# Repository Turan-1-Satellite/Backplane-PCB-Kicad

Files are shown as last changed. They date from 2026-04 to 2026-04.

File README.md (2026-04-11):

# Turan-1 Backplane PCB in KiCad
## About
This repository contains the KiCad 9.0 project files for the TURAN-1 Backplane PCB.

## Requirements
- KiCad 9.0 or later

## First Set up
All required custom libraries and 3D models are included as a git submodule. To clone the repository together with custom libraries, you need to recursively clone it:
```
git clone --recurse-submodules https://github.com/Turan-1-Satellite/Backplane-PCB-Kicad.git
```

## Open the Project
Open the BP-PCB-Kicad.kicad_pro file from the project root directory.

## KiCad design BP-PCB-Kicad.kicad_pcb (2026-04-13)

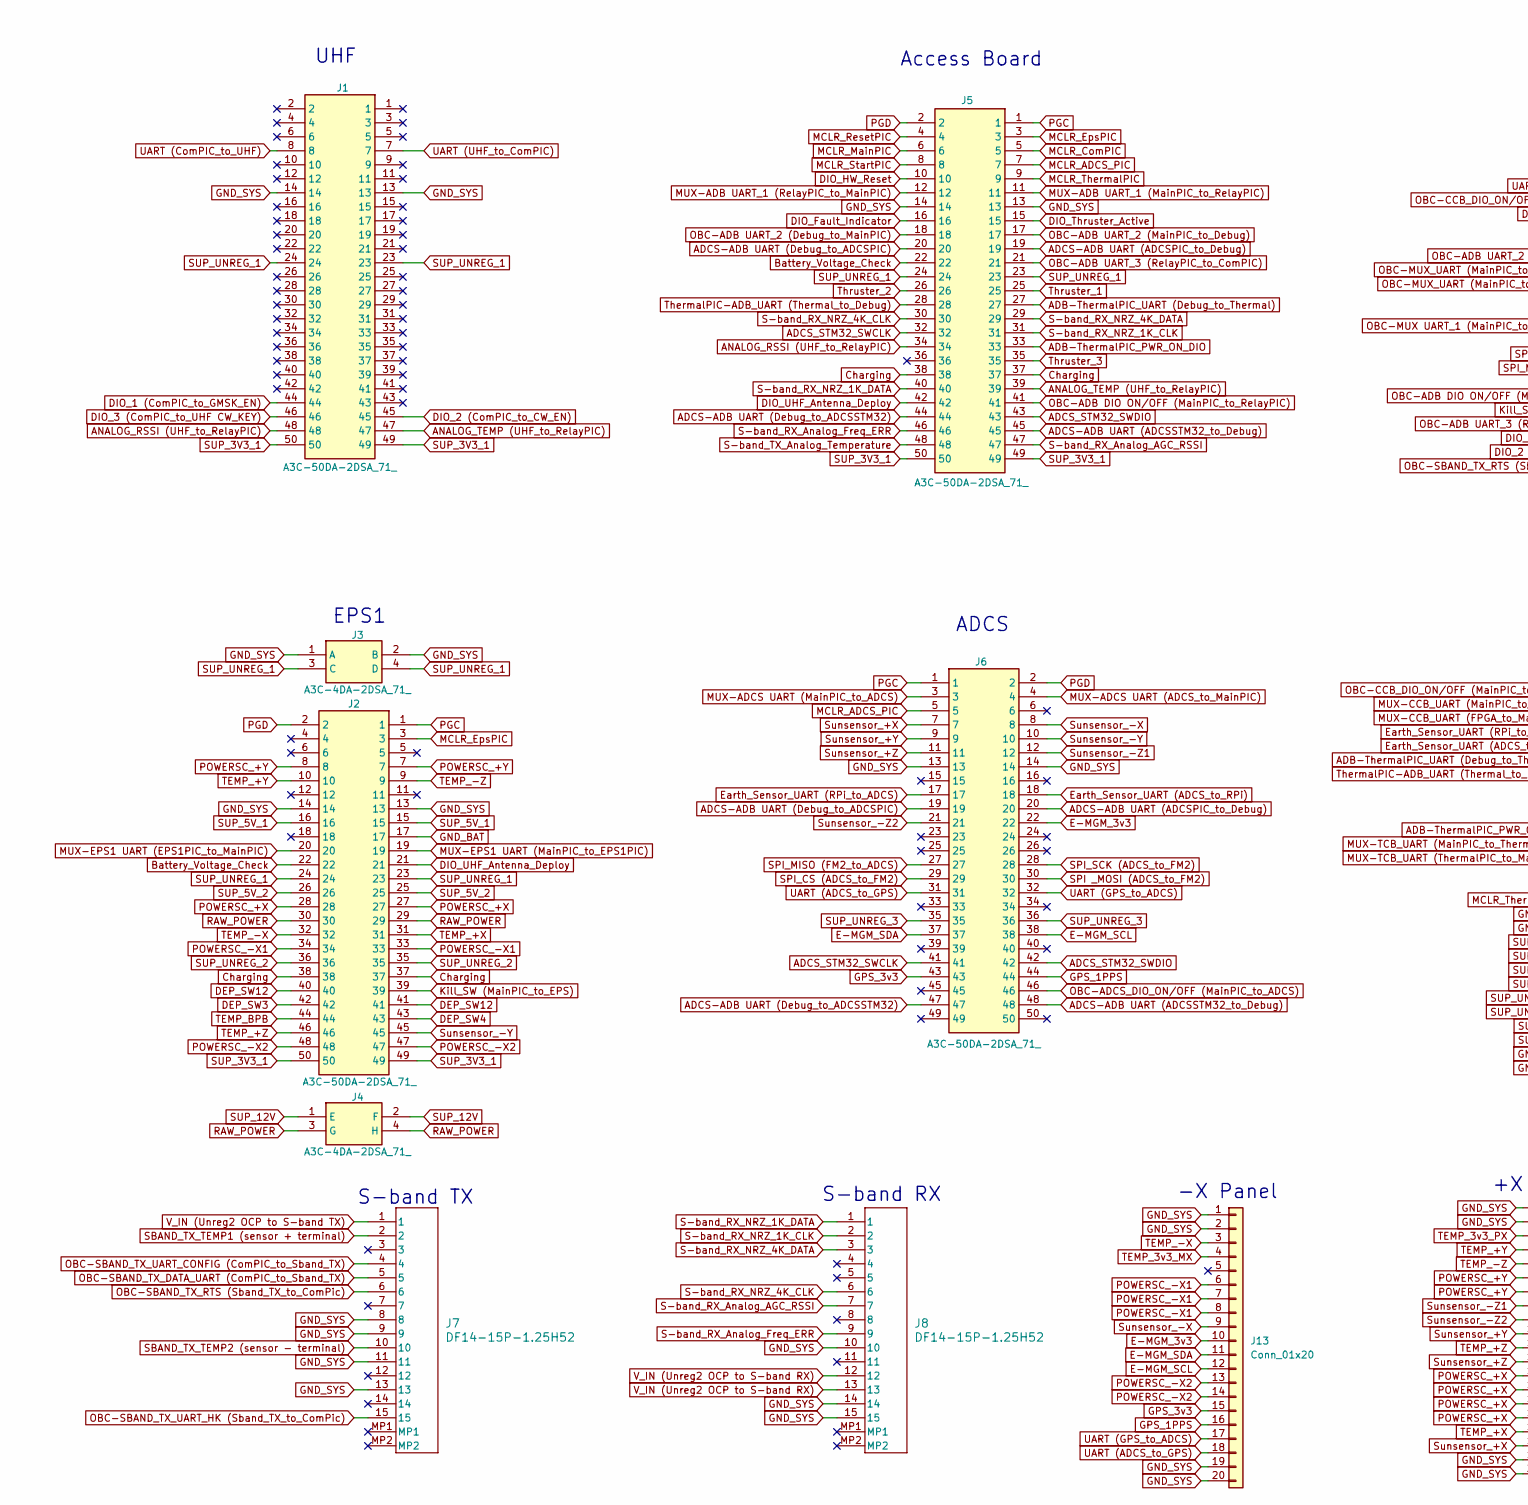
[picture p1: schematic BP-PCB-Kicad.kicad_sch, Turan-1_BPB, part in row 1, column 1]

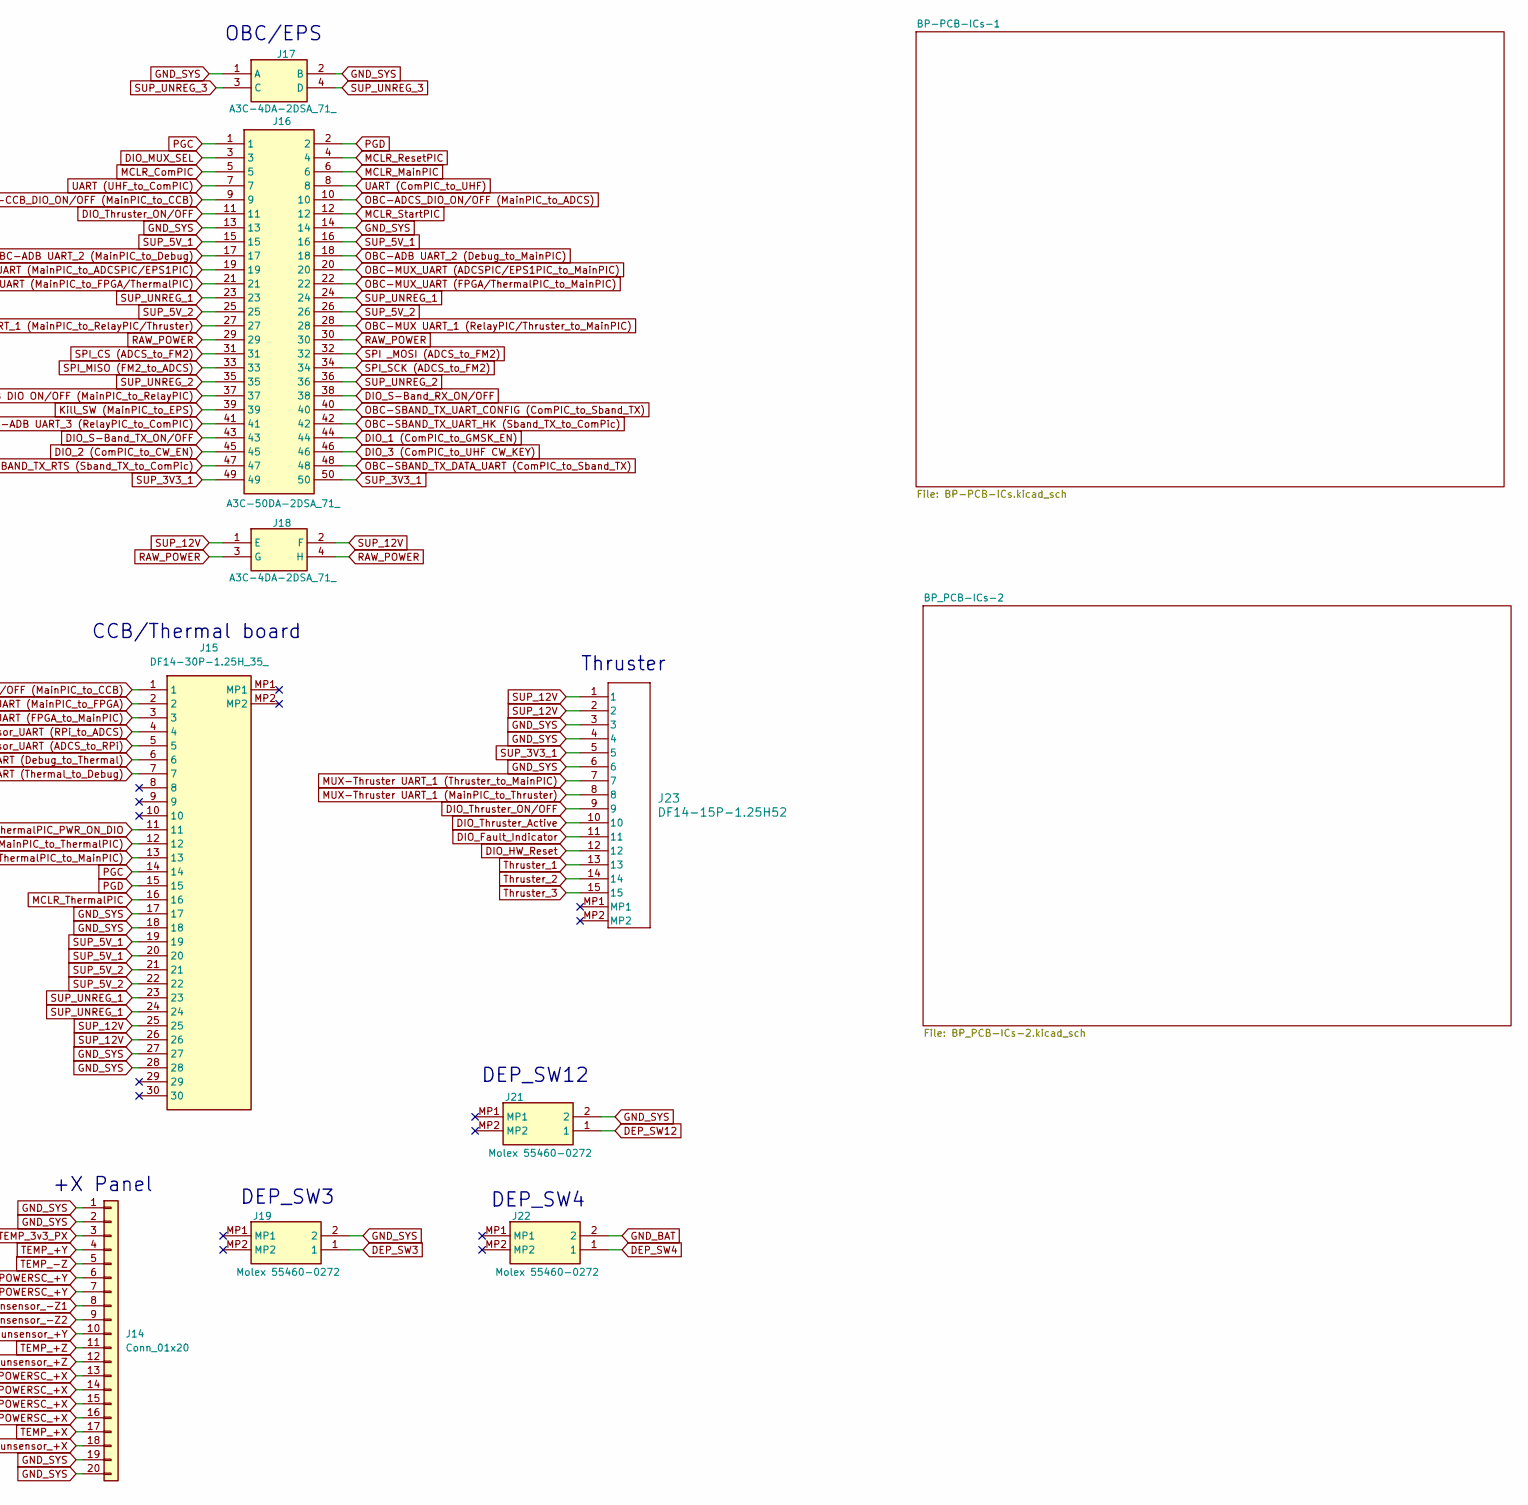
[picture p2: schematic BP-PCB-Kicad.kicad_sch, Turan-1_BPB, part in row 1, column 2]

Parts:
J1, J2, J5: A3C-50DA-2DSA_71_; Hirose_A3C-50DA-2DSC(71)_Mirrored; Mouser Part Number 798-A3C-50DA-2DSA71
J3, J4: A3C-4DA-2DSA_71_; Hirose_A3C-4DA-2DSA(71)_Mirrored; Mouser Part Number 798-A3C-4DA-2DSA71
J6, J16: A3C-50DA-2DSA_71_; Hirose_A3C-50DA-2DSC(71); Mouser Part Number 798-A3C-50DA-2DSA71
J7, J8, J23: DF14-15P-1.25H52; Hirose_DF14-15P-1.25H(52)
J13: Conn_01x20; PSR-420253-10
J14: Conn_01x20; PSR-420253-10_Mirrored
J15: DF14-30P-1.25H_35_; Hirose_DF14-30P-1.25H(35); Mouser Part Number 798-DF1430P125H35
J17, J18: A3C-4DA-2DSA_71_; Hirose_A3C-4DA-2DSA(71); Mouser Part Number 798-A3C-4DA-2DSA71
J19, J21, J22: Molex 55460-0272; Molex_0554600272; Mouser Part Number 538-55460-0272

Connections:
V_IN (Unreg2 OCP to S-band RX): J8.12, J8.13; also elsewhere on the board
V_IN (Unreg2 OCP to S-band TX): J7.1; also elsewhere on the board
ADB-ThermalPIC_PWR_ON_DIO: J5.33, J15.11
ADB-ThermalPIC_UART (Debug_to_Thermal): J5.27, J15.6
ADCS-ADB UART (ADCSPIC_to_Debug): J5.19, J6.20
ADCS-ADB UART (ADCSSTM32_to_Debug): J5.45, J6.48
ADCS-ADB UART (Debug_to_ADCSPIC): J5.20, J6.19
ADCS-ADB UART (Debug_to_ADCSSTM32): J5.44, J6.47
ADCS_STM32_SWCLK: J5.32, J6.41
ADCS_STM32_SWDIO: J5.43, J6.42
ANALOG_RSSI (UHF_to_RelayPIC): J1.48, J5.34
ANALOG_TEMP (UHF_to_RelayPIC): J1.47, J5.39
Battery_Voltage_Check: J2.22, J5.22
Charging: J2.37, J2.38, J5.37, J5.38
DEP_SW3: J2.42, J19.1
DEP_SW4: J2.43, J22.1
DEP_SW12: J2.40, J2.41, J21.1
DIO_1 (ComPIC_to_GMSK_EN): J1.44, J16.44
DIO_2 (ComPIC_to_CW_EN): J1.45, J16.45
DIO_3 (ComPIC_to_UHF CW_KEY): J1.46, J16.46
DIO_Fault_Indicator: J5.16, J23.11
DIO_HW_Reset: J5.10, J23.12
DIO_MUX_SEL: J16.3; also elsewhere on the board
DIO_S-Band_RX_ON/OFF: J16.38; also elsewhere on the board
DIO_S-Band_TX_ON/OFF: J16.43; also elsewhere on the board
DIO_Thruster_Active: J5.15, J23.10
DIO_Thruster_ON/OFF: J16.11, J23.9
DIO_UHF_Antenna_Deploy: J2.21, J5.42
E-MGM_3v3: J6.22, J13.10
E-MGM_SCL: J6.38, J13.12
E-MGM_SDA: J6.37, J13.11
Earth_Sensor_UART (ADCS_to_RPi): J6.18, J15.5
Earth_Sensor_UART (RPi_to_ADCS): J6.17, J15.4
GND_BAT: J2.17, J22.2
GND_SYS: J1.13, J1.14, J2.13, J2.14, J3.1 (A), J3.2 (B), J5.13, J5.14, J6.13, J6.14, J7.8, J7.9, J7.11, J7.13, J8.10, J8.14, J8.15, J13.1, J13.2, J13.19, J13.20, J14.1, J14.2, J14.19, J14.20, J15.17, J15.18, J15.27, J15.28, J16.13, J16.14, J17.1 (A), J17.2 (B), J19.2, J21.2, J23.3, J23.4, J23.6; also elsewhere on the board
GPS_1PPS: J6.44, J13.16
GPS_3v3: J6.43, J13.15
Kill_SW (MainPIC_to_EPS): J2.39, J16.39
MCLR_ADCS_PIC: J5.7, J6.5
MCLR_ComPIC: J5.5, J16.5
MCLR_EpsPIC: J2.3, J5.3
MCLR_MainPIC: J5.6, J16.6
MCLR_ResetPIC: J5.4, J16.4
MCLR_StartPIC: J5.8, J16.12
MCLR_ThermalPIC: J5.9, J15.16
MUX-ADB UART_1 (MainPIC_to_RelayPIC): J5.11; also elsewhere on the board
MUX-ADB UART_1 (RelayPIC_to_MainPIC): J5.12; also elsewhere on the board
MUX-ADCS UART (ADCS_to_MainPIC): J6.4; also elsewhere on the board
MUX-ADCS UART (MainPIC_to_ADCS): J6.3; also elsewhere on the board
MUX-CCB_UART (FPGA_to_MainPIC): J15.3; also elsewhere on the board
MUX-CCB_UART (MainPIC_to_FPGA): J15.2; also elsewhere on the board
MUX-EPS1 UART (EPS1PIC_to_MainPIC): J2.20; also elsewhere on the board
MUX-EPS1 UART (MainPIC_to_EPS1PIC): J2.19; also elsewhere on the board
MUX-TCB_UART (MainPIC_to_ThermalPIC): J15.12; also elsewhere on the board
MUX-TCB_UART (ThermalPIC_to_MainPIC): J15.13; also elsewhere on the board
MUX-Thruster UART_1 (MainPIC_to_Thruster): J23.8; also elsewhere on the board
MUX-Thruster UART_1 (Thruster_to_MainPIC): J23.7; also elsewhere on the board
OBC-ADB DIO ON/OFF (MainPIC_to_RelayPIC): J5.41, J16.37
OBC-ADB UART_2 (Debug_to_MainPIC): J5.18, J16.18
OBC-ADB UART_2 (MainPIC_to_Debug): J5.17, J16.17
OBC-ADB UART_3 (RelayPIC_to_ComPIC): J5.21, J16.41
OBC-ADCS_DIO_ON/OFF (MainPIC_to_ADCS): J6.46, J16.10
OBC-CCB_DIO_ON/OFF (MainPIC_to_CCB): J15.1, J16.9
OBC-MUX UART_1 (MainPIC_to_RelayPIC/Thruster): J16.27; also elsewhere on the board
OBC-MUX UART_1 (RelayPIC/Thruster_to_MainPIC): J16.28; also elsewhere on the board
OBC-MUX_UART (ADCSPIC/EPS1PIC_to_MainPIC): J16.20; also elsewhere on the board
OBC-MUX_UART (FPGA/ThermalPIC_to_MainPIC): J16.22; also elsewhere on the board
OBC-MUX_UART (MainPIC_to_ADCSPIC/EPS1PIC): J16.19; also elsewhere on the board
OBC-MUX_UART (MainPIC_to_FPGA/ThermalPIC): J16.21; also elsewhere on the board
OBC-SBAND_TX_DATA_UART (ComPIC_to_Sband_TX): J7.5, J16.48
OBC-SBAND_TX_RTS (Sband_TX_to_ComPic): J7.6, J16.47
OBC-SBAND_TX_UART_CONFIG (ComPIC_to_Sband_TX): J7.4, J16.40
OBC-SBAND_TX_UART_HK (Sband_TX_to_ComPic): J7.15, J16.42
PGC: J2.1, J5.1, J6.1, J15.14, J16.1
PGD: J2.2, J5.2, J6.2, J15.15, J16.2
POWERSC_+X: J2.27, J2.28, J14.13, J14.14, J14.15, J14.16
POWERSC_+Y: J2.7, J2.8, J14.6, J14.7
POWERSC_-X1: J2.33, J2.34, J13.6, J13.7, J13.8
POWERSC_-X2: J2.47, J2.48, J13.13, J13.14
RAW_POWER: J2.29, J2.30, J4.3 (G), J4.4 (H), J16.29, J16.30, J18.3 (G), J18.4 (H)
S-band_RX_Analog_AGC_RSSI: J5.47, J8.7
S-band_RX_Analog_Freq_ERR: J5.46, J8.9
S-band_RX_NRZ_1K_CLK: J5.31, J8.2
S-band_RX_NRZ_1K_DATA: J5.40, J8.1
S-band_RX_NRZ_4K_CLK: J5.30, J8.6
S-band_RX_NRZ_4K_DATA: J5.29, J8.3
S-band_TX_Analog_Temperature: J5.48, J7.10; also elsewhere on the board
SBAND_TX_TEMP1 (sensor + terminal): J7.2; also elsewhere on the board
SPI _MOSI (ADCS_to_FM2): J6.30, J16.32
SPI_CS (ADCS_to_FM2): J6.29, J16.31
SPI_MISO (FM2_to_ADCS): J6.27, J16.33
SPI_SCK (ADCS_to_FM2): J6.28, J16.34
SUP_3V3_1: J1.49, J1.50, J2.49, J2.50, J5.49, J5.50, J16.49, J16.50, J23.5; also elsewhere on the board
SUP_5V_1: J2.15, J2.16, J15.19, J15.20, J16.15, J16.16; also elsewhere on the board
SUP_5V_2: J2.25, J2.26, J15.21, J15.22, J16.25, J16.26
SUP_12V: J4.1 (E), J4.2 (F), J15.25, J15.26, J18.1 (E), J18.2 (F), J23.1, J23.2
SUP_UNREG_1: J1.23, J1.24, J2.23, J2.24, J3.3 (C), J3.4 (D), J5.23, J5.24, J15.23, J15.24, J16.23, J16.24
SUP_UNREG_2: J2.35, J2.36, J16.35, J16.36; also elsewhere on the board
SUP_UNREG_3: J6.35, J6.36, J17.3 (C), J17.4 (D)
Sunsensor_+X: J6.7, J14.18
Sunsensor_+Y: J6.9, J14.10
Sunsensor_+Z: J6.11, J14.12
Sunsensor_-X: J6.8, J13.9
Sunsensor_-Y: J2.45, J6.10
Sunsensor_-Z1: J6.12, J14.8
Sunsensor_-Z2: J6.21, J14.9
TEMP_3v3_MX: J13.4; also elsewhere on the board
TEMP_3v3_PX: J14.3; also elsewhere on the board
TEMP_+X: J2.31, J14.17
TEMP_+Y: J2.10, J14.4
TEMP_+Z: J2.46, J14.11
TEMP_-X: J2.32, J13.3
TEMP_-Z: J2.9, J14.5
TEMP_BPB: J2.44; also elsewhere on the board
ThermalPIC-ADB_UART (Thermal_to_Debug): J5.28, J15.7
Thruster_1: J5.25, J23.13
Thruster_2: J5.26, J23.14
Thruster_3: J5.35, J23.15
UART (ADCS_to_GPS): J6.31, J13.18
UART (ComPIC_to_UHF): J1.8, J16.8
UART (GPS_to_ADCS): J6.32, J13.17
UART (UHF_to_ComPIC): J1.7, J16.7

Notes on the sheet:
DEP_SW4
OBC/EPS
ADCS
S-band TX
EPS1
DEP_SW3
+X Panel
CCB/Thermal board
DEP_SW12
S-band RX
UHF
Access Board
Thruster
-X Panel

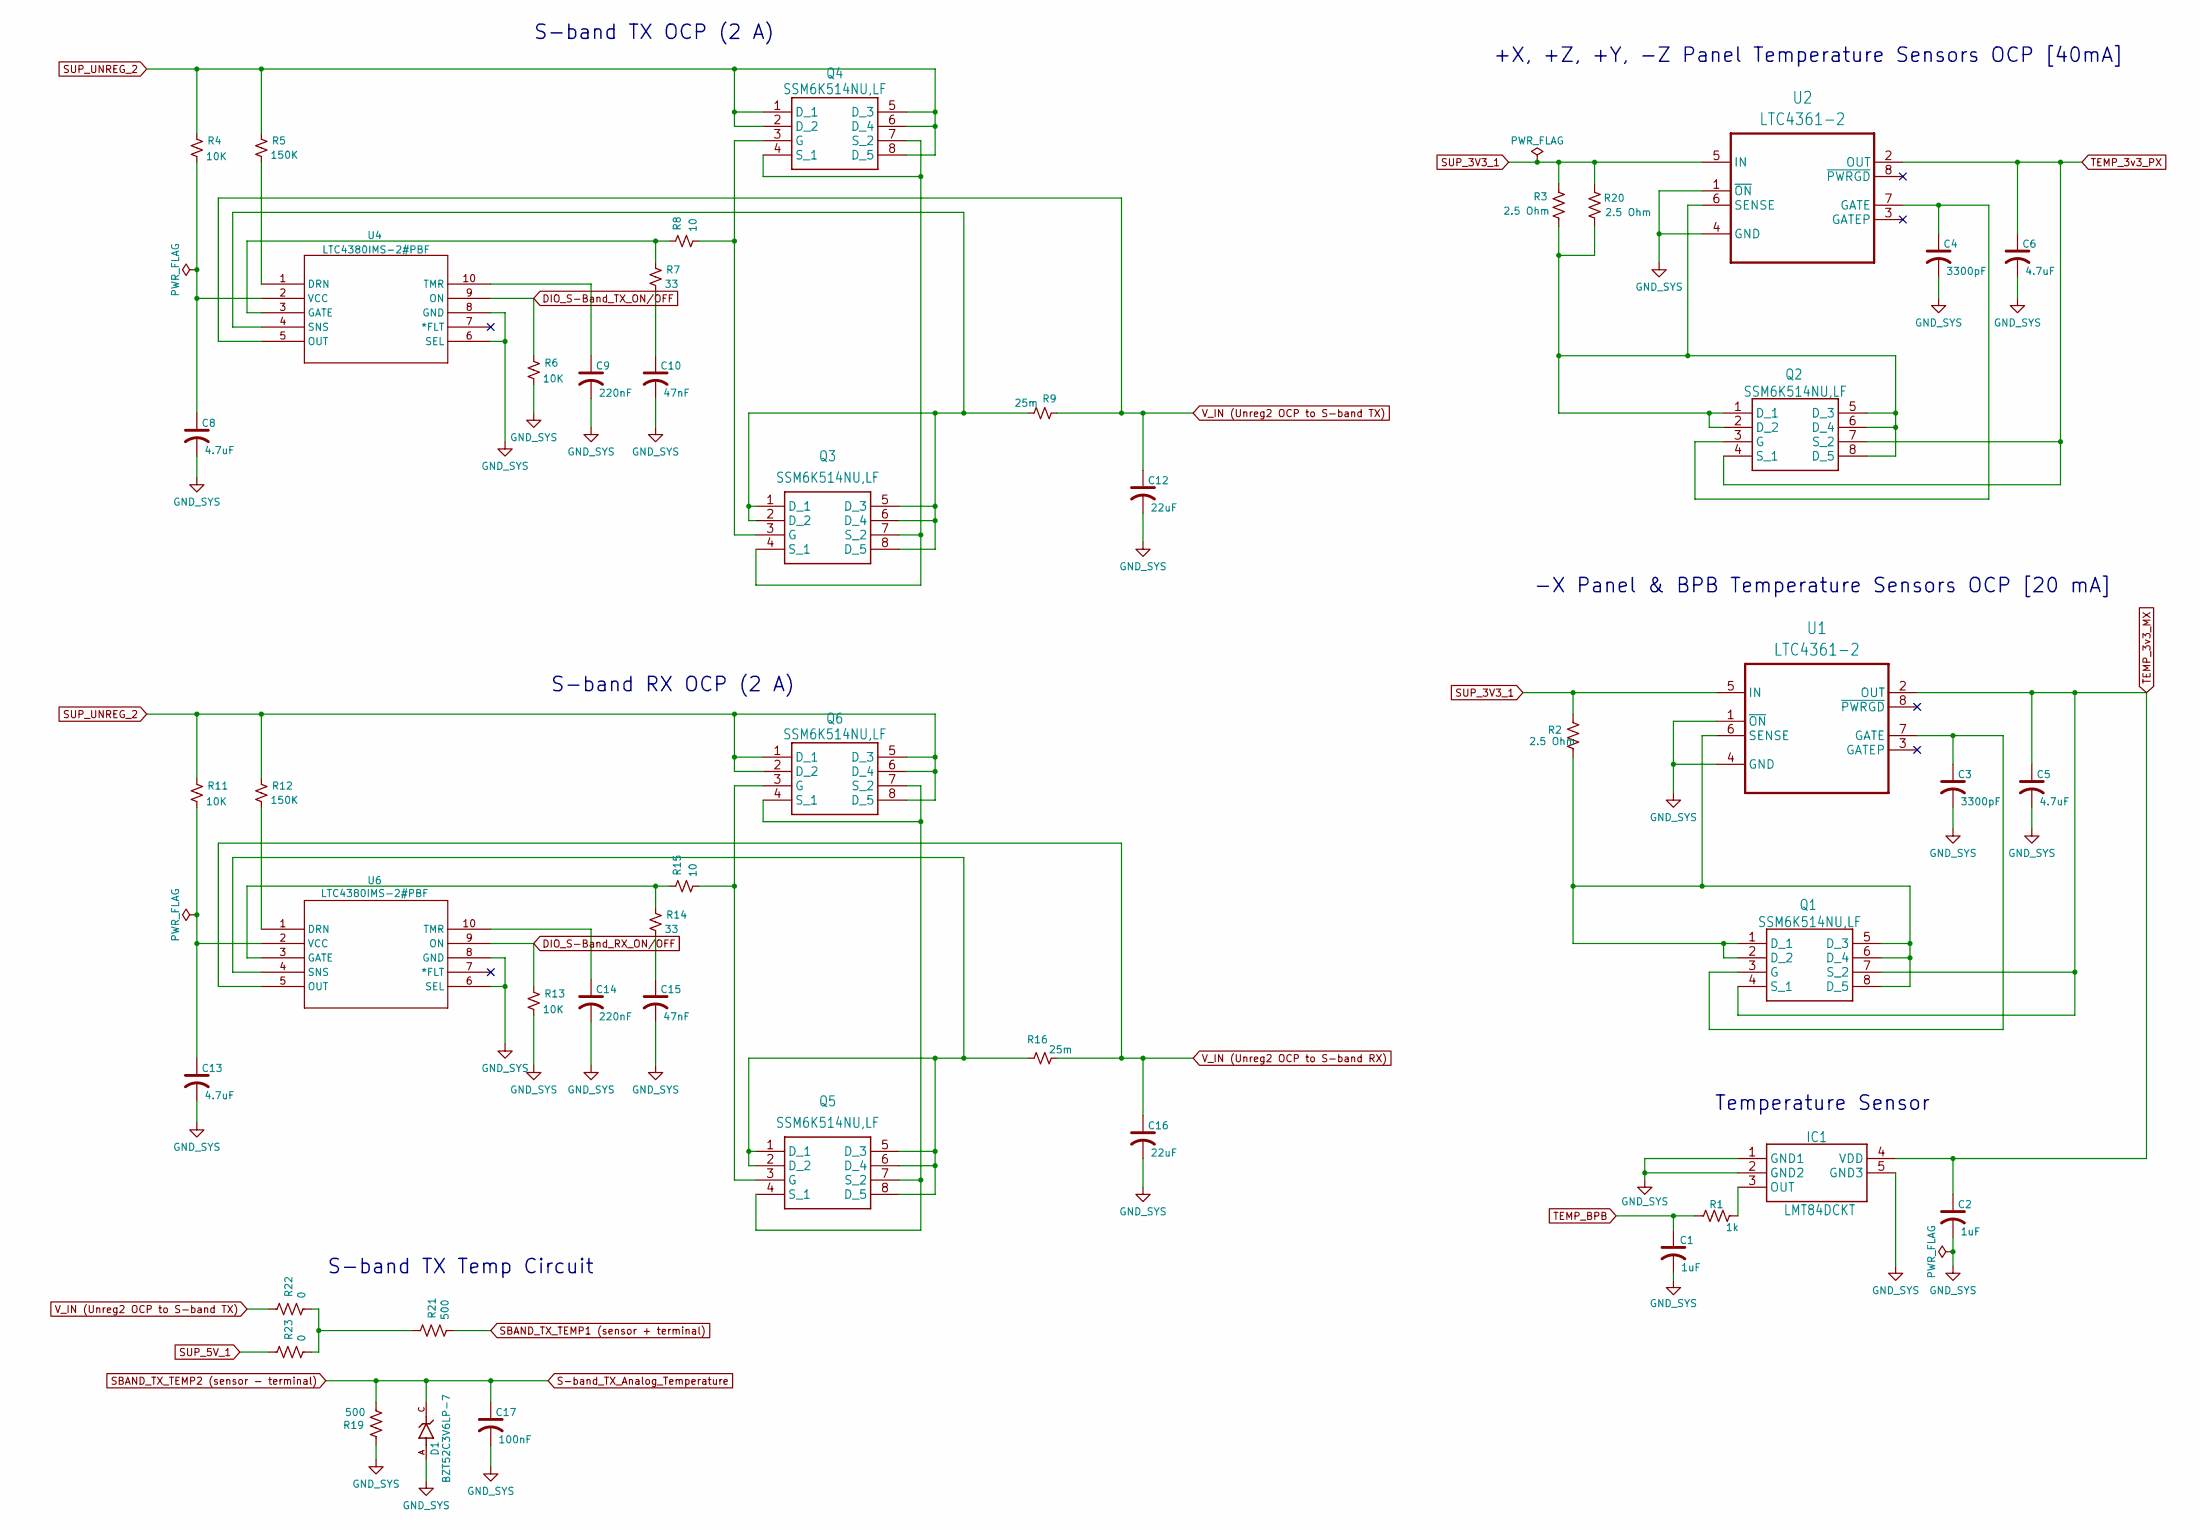
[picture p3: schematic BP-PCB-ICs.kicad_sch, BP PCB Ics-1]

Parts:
C1, C2: 1uF; C_0805_2012Metric; LCSC Part C1712
C3, C4: 3300pF; C_0805_2012Metric; LCSC Part C77062
C5, C6, C8, C13: 4.7uF; C_0805_2012Metric; LCSC Part C1746
C9, C14: 220nF; C_0805_2012Metric; LCSC Part C1770
C10, C15: 47nF; C_0805_2012Metric; LCSC Part C1745
C12, C16: 22uF; C_0805_2012Metric; LCSC Part C45783
C17: 100nF; C_0805_2012Metric; LCSC Part C29926
D1: BZT52C3V6LP-7; DIO_BZT52C3V6LP-7; LCSC Part C151430
IC1: LMT84DCKT; LCSC Part C2860524
Q1, Q2, Q3, Q4, Q5, Q6: SSM6K514NU,LF; SSM6K514NULF; LCSC Part C6235373
R1: 1k; R_0805_2012Metric; LCSC Part C702831
R2, R3, R20: 2.5 Ohm; R_0805_2012Metric; LCSC Part C409739
R4, R6, R11, R13: 10K; R_0805_2012Metric; LCSC Part C702829
R5, R12: 150K; R_0805_2012Metric; LCSC Part C17470
R7, R14: 33; R_0805_2012Metric; LCSC Part C49330262
R8, R15: 10; R_0805_2012Metric; LCSC Part C702857
R9, R16: 25m; R_0805_2012Metric; LCSC Part C858607
R19, R21: 500; R_0805_2012Metric; LCSC Part C2828711
R22: 0; R_0805_2012Metric
R23: 0; R_0805_2012Metric; LCSC Part C702869
U1, U2: LTC4361-2; LTC4361HTS8; LCSC Part C688273
U4, U6: LTC4380IMS-2#PBF; LCSC Part C688471

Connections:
V_IN (Unreg2 OCP to S-band RX): C16.1, R16.2, U6.5 (OUT); also elsewhere on the board
V_IN (Unreg2 OCP to S-band TX): C12.1, R9.2, R22.1, U4.5 (OUT); also elsewhere on the board
DIO_S-Band_RX_ON/OFF: R13.1, U6.9 (ON); also elsewhere on the board
DIO_S-Band_TX_ON/OFF: R6.1, U4.9 (ON); also elsewhere on the board
GND_SYS: C1.2, C2.2, C3.2, C4.2, C5.2, C6.2, C8.2, C9.2, C10.2, C12.2, C13.2, C14.2, C15.2, C16.2, C17.2, D1.A, IC1.1 (GND1), IC1.2 (GND2), IC1.5 (GND3), R6.2, R13.2, R19.1, U1.1 (~ON), U1.4 (GND), U2.1 (~ON), U2.4 (GND), U4.6 (SEL), U4.8 (GND), U6.6 (SEL), U6.8 (GND); also elsewhere on the board
unnamed: C10.1, R7.2
unnamed: C15.1, R14.2
unnamed: IC1.3 (OUT), R1.2
unnamed: Q1.1 (D_1), Q1.2 (D_2), Q1.5 (D_3), Q1.6 (D_4), Q1.8 (D_5), R2.2, U1.6 (SENSE)
unnamed: C3.1, Q1.3 (G), U1.7 (GATE)
unnamed: Q2.1 (D_1), Q2.2 (D_2), Q2.5 (D_3), Q2.6 (D_4), Q2.8 (D_5), R3.2, R20.2, U2.6 (SENSE)
unnamed: C4.1, Q2.3 (G), U2.7 (GATE)
unnamed: Q3.1 (D_1), Q3.2 (D_2), Q3.5 (D_3), Q3.6 (D_4), Q3.8 (D_5), R9.1, U4.4 (SNS)
unnamed: Q3.3 (G), Q4.3 (G), R8.2
unnamed: Q3.4 (S_1), Q3.7 (S_2), Q4.4 (S_1), Q4.7 (S_2)
unnamed: Q5.1 (D_1), Q5.2 (D_2), Q5.5 (D_3), Q5.6 (D_4), Q5.8 (D_5), R16.1, U6.4 (SNS)
unnamed: Q5.3 (G), Q6.3 (G), R15.2
unnamed: Q5.4 (S_1), Q5.7 (S_2), Q6.4 (S_1), Q6.7 (S_2)
unnamed: R21.1, R22.2, R23.2
unnamed: R5.2, U4.1 (DRN)
unnamed: R7.1, R8.1, U4.3 (GATE)
unnamed: C9.1, U4.10 (TMR)
unnamed: C8.1, R4.2, U4.2 (VCC)
unnamed: R12.2, U6.1 (DRN)
unnamed: R14.1, R15.1, U6.3 (GATE)
unnamed: C14.1, U6.10 (TMR)
unnamed: C13.1, R11.2, U6.2 (VCC)
S-band_TX_Analog_Temperature: C17.1, D1.C, R19.2; also elsewhere on the board
SBAND_TX_TEMP1 (sensor + terminal): R21.2; also elsewhere on the board
SUP_3V3_1: R2.1, R3.1, R20.1, U1.5 (IN), U2.5 (IN); also elsewhere on the board
SUP_5V_1: R23.1; also elsewhere on the board
SUP_UNREG_2: Q4.1 (D_1), Q4.2 (D_2), Q4.5 (D_3), Q4.6 (D_4), Q4.8 (D_5), Q6.1 (D_1), Q6.2 (D_2), Q6.5 (D_3), Q6.6 (D_4), Q6.8 (D_5), R4.1, R5.1, R11.1, R12.1; also elsewhere on the board
TEMP_3v3_MX: C2.1, C5.1, IC1.4 (VDD), Q1.4 (S_1), Q1.7 (S_2), U1.2 (OUT); also elsewhere on the board
TEMP_3v3_PX: C6.1, Q2.4 (S_1), Q2.7 (S_2), U2.2 (OUT); also elsewhere on the board
TEMP_BPB: C1.1, R1.1; also elsewhere on the board

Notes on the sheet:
S-band TX Temp Circuit
Temperature Sensor
+X, +Z, +Y, -Z Panel Temperature Sensors OCP [40mA]
-X Panel & BPB Temperature Sensors OCP [20 mA]
S-band TX OCP (2 A)
S-band RX OCP (2 A)

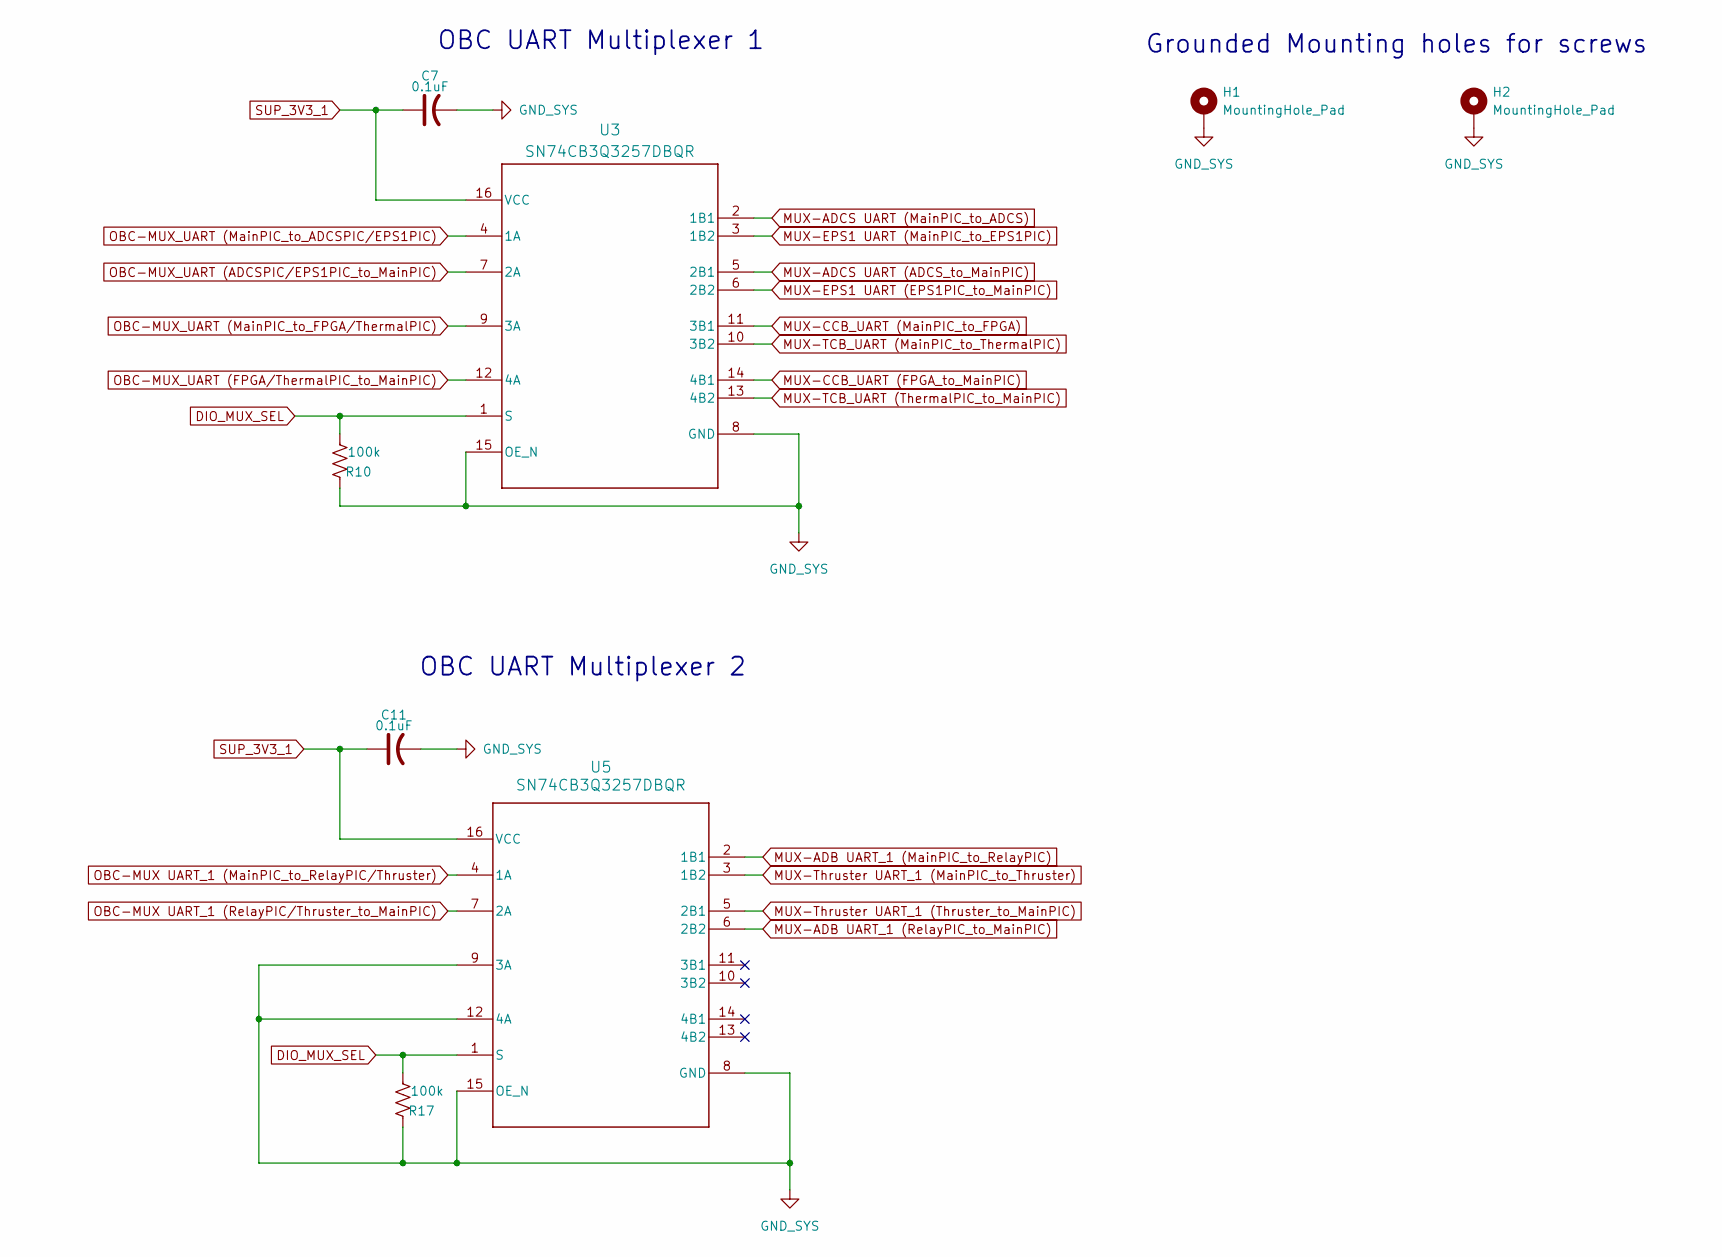
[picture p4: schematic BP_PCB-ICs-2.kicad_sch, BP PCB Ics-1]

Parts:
C7, C11: 0.1uF; C_0805_2012Metric; LCSC Part C1711
H1, H2: MountingHole_Pad; MountingHole_2.7mm_Pad
R10, R17: 100k; R_0805_2012Metric; LCSC Part C409739
U3, U5: SN74CB3Q3257DBQR; LCSC Part C7138

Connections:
DIO_MUX_SEL: R10.2, R17.2, U3.1 (S), U5.1 (S); also elsewhere on the board
GND_SYS: C7.2, C11.2, H1.1, H2.1, R10.1, R17.1, U3.8 (GND), U3.15 (OE_N), U5.8 (GND), U5.9 (3A), U5.12 (4A), U5.15 (OE_N); also elsewhere on the board
MUX-ADB UART_1 (MainPIC_to_RelayPIC): U5.2 (1B1); also elsewhere on the board
MUX-ADB UART_1 (RelayPIC_to_MainPIC): U5.6 (2B2); also elsewhere on the board
MUX-ADCS UART (ADCS_to_MainPIC): U3.5 (2B1); also elsewhere on the board
MUX-ADCS UART (MainPIC_to_ADCS): U3.2 (1B1); also elsewhere on the board
MUX-CCB_UART (FPGA_to_MainPIC): U3.14 (4B1); also elsewhere on the board
MUX-CCB_UART (MainPIC_to_FPGA): U3.11 (3B1); also elsewhere on the board
MUX-EPS1 UART (EPS1PIC_to_MainPIC): U3.6 (2B2); also elsewhere on the board
MUX-EPS1 UART (MainPIC_to_EPS1PIC): U3.3 (1B2); also elsewhere on the board
MUX-TCB_UART (MainPIC_to_ThermalPIC): U3.10 (3B2); also elsewhere on the board
MUX-TCB_UART (ThermalPIC_to_MainPIC): U3.13 (4B2); also elsewhere on the board
MUX-Thruster UART_1 (MainPIC_to_Thruster): U5.3 (1B2); also elsewhere on the board
MUX-Thruster UART_1 (Thruster_to_MainPIC): U5.5 (2B1); also elsewhere on the board
OBC-MUX UART_1 (MainPIC_to_RelayPIC/Thruster): U5.4 (1A); also elsewhere on the board
OBC-MUX UART_1 (RelayPIC/Thruster_to_MainPIC): U5.7 (2A); also elsewhere on the board
OBC-MUX_UART (ADCSPIC/EPS1PIC_to_MainPIC): U3.7 (2A); also elsewhere on the board
OBC-MUX_UART (FPGA/ThermalPIC_to_MainPIC): U3.12 (4A); also elsewhere on the board
OBC-MUX_UART (MainPIC_to_ADCSPIC/EPS1PIC): U3.4 (1A); also elsewhere on the board
OBC-MUX_UART (MainPIC_to_FPGA/ThermalPIC): U3.9 (3A); also elsewhere on the board
SUP_3V3_1: C7.1, C11.1, U3.16 (VCC), U5.16 (VCC); also elsewhere on the board

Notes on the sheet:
Grounded Mounting holes for screws
OBC UART Multiplexer 1
OBC UART Multiplexer 2

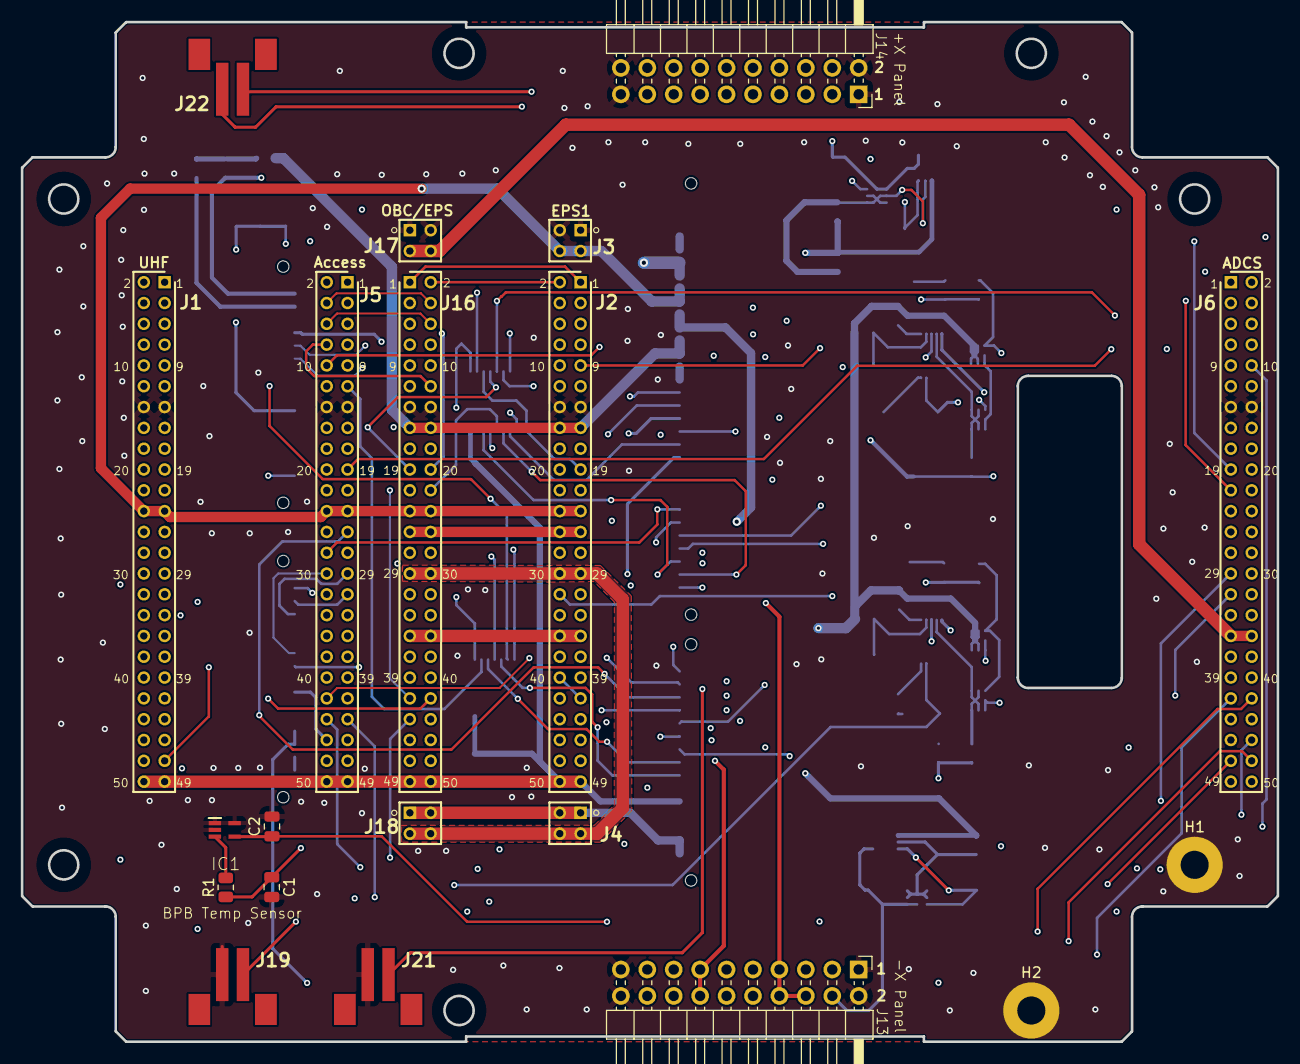
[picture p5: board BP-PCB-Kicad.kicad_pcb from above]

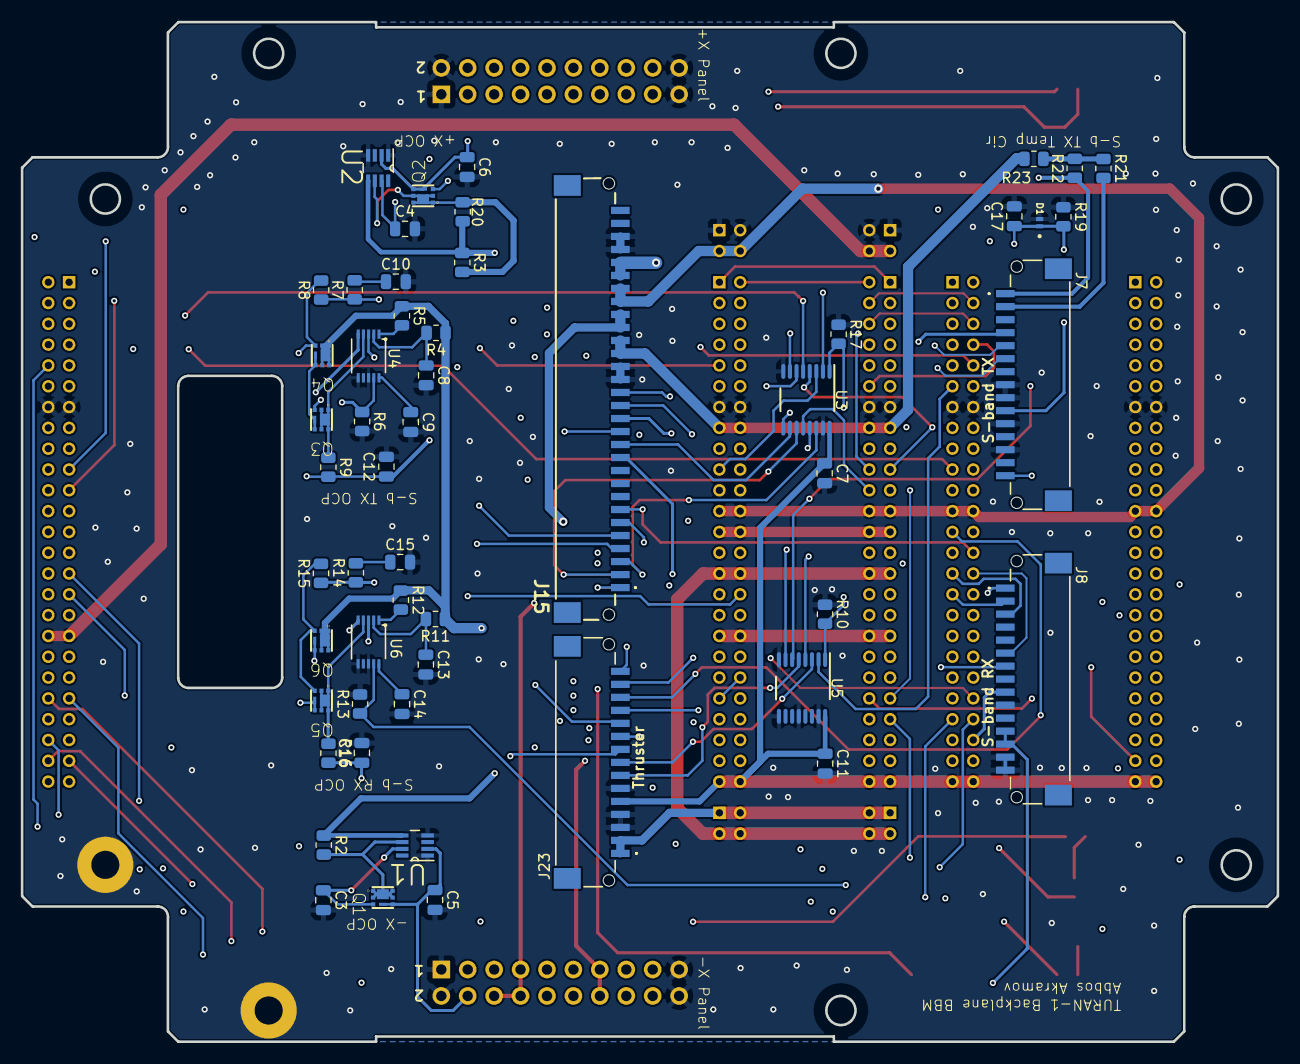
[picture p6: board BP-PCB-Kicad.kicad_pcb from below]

Board: 4 copper layers, 120.7 x 98.0 mm, 73 parts (53 on the bottom side), 144 nets.

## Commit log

2026-03-01 All connectors mounted on BPB v2-2026-02-27 as structure's documentation
    [BP-PCB-Kicad.kicad_pcb, BP-PCB-Kicad.kicad_sch, Hirose A3C-4DA-2DSA(71).step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]
2026-03-04 Add KiCad-Libraries as git submodule
    Links to https://github.com/Turan-1-Satellite/KiCad-Libraries.git
2026-03-04 Git Submodule added inside <KiCad-Libaries> folder to share libraries across different projects
    [BP-PCB-Kicad.kicad_pcb, BP-PCB-Kicad.kicad_sch, Hirose A3C-4DA-2DSA(71).step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]
2026-03-04 Feature: added git submodule for kicad shared libraries
    [BP-PCB-Kicad.kicad_pcb, BP-PCB-Kicad.kicad_sch, Hirose A3C-4DA-2DSA(71).step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]
2026-03-05 Update .gitignore and symbol library table for KiCad submodule integration
2026-03-10 Customized to the latest version of the Custom KiCad-Library
    [BP-PCB-Kicad.kicad_pcb]
2026-03-10 Revise README for Turan-1 Backplane PCB
    Updated project title and improved formatting in README.
2026-03-11 Adjusted to libraries
    [BP-PCB-Kicad.kicad_pcb, BP-PCB-Kicad.kicad_sch]
2026-03-23 Added ICs to schematic
    [BP-PCB-ICs.kicad_sch]
2026-03-24 Fixed errors in schematics
    [BP-PCB-ICs.kicad_sch, BP-PCB-Kicad.kicad_pcb, BP-PCB-Kicad.kicad_sch]
2026-03-26 Synchronized with pin mapping table and added circuits
    [BP-PCB-Kicad.kicad_pcb, BP-PCB-Kicad.kicad_sch, BP_PCB-ICs-2.kicad_sch]
2026-03-26 -X temp OCP is being shared with BP
    [BP-PCB-ICs.kicad_sch]
2026-03-30 PCB layout is syncronized with schematic
    [BP-PCB-ICs.kicad_sch, BP-PCB-Kicad.kicad_pcb, BP-PCB-Kicad.kicad_sch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]
2026-04-04 Microelectronic components placed onto the back of BPB
    [BP-PCB-ICs.kicad_sch, BP-PCB-Kicad.kicad_pcb, BP-PCB-Kicad.kicad_sch]
2026-04-06 Routing traces of panels
    [BP-PCB-Kicad.kicad_pcb, BP-PCB-Kicad.kicad_sch]
2026-04-09 Finished routing and NO DRC errors
    [BP-PCB-ICs.kicad_sch, BP-PCB-Kicad.kicad_pcb, BP_PCB-ICs-2.kicad_sch]
2026-04-09 Final routing v2
    [BP-PCB-Kicad.kicad_pcb]
2026-04-10 ERC errors eleminated from schematic
    [BP-PCB-ICs.kicad_sch]
2026-04-11 Corrected OCP values in schematic and fixed PCB layout
    [BP-PCB-ICs.kicad_sch, BP-PCB-Kicad.kicad_pcb, BP-PCB-Kicad.kicad_sch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]
2026-04-12 Added grounded mounting holes to schematics
    [BP-PCB-Kicad.kicad_pcb, BP_PCB-ICs-2.kicad_sch]
2026-04-13 Polished some power lines
    [BP-PCB-Kicad.kicad_pcb]
2026-04-13 Updated solder mask expension
2026-04-13 BBM version requested for fabrication
    [BP-PCB-ICs.kicad_sch, BP-PCB-Kicad.kicad_pcb]
